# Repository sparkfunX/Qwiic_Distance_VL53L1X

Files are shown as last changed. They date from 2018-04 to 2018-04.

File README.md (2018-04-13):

SparkFun Qwiic 4m Distance Sensor with VL53L1X
========================================

SparkFun Distance Sensor 4m Qwiic - VL53L1X

[*SparkX Distance Sensor 4m (Qwiic) - VL53L1X (SPX-14667)*](https://www.sparkfun.com/products/14667)

The VL53L1X is the latest Time Of Flight (ToF) sensor to be released. It uses a VCSEL (vertical cavity surface emitting laser) to emit a class 1 IR laser and time the reflection to the target. What does all this mean? You can measure the distance to an object up to 4 meters away with millimeter resolution! That’s pretty incredible.

We’re far from done: The VL53L1X is a highly complex sensor with a multitude of options and configurations. We’ve written example sketches that allow you to read the distance, signal rate, and range status. Because ST has chosen not to release a complete datasheet we are forced to reverse engineer the interface from their example code and I2C data stream captures. If you’re into puzzles we could use your help to make the library better!

We’ve found the precision of the sensor to be 1mm but the accuracy is around +/-5mm.

SparkFun labored with love to create this code. Feel like supporting open source hardware? 
Buy a [breakout board](https://www.sparkfun.com/products/14667) from SparkFun!

Repository Contents
-------------------

* **/Documents** - Datasheets
* **/DataCapture** - A capture of the I2C traffic from the ST X-NUCLEO-53L1A1 evaluation kit.
* **/Hardware** - Eagle design files (.brd, .sch)
* **/Software** - Processing Example showing how to manipulate graphics using quaternions

Library
--------------
* **[Arduino Library](https://github.com/sparkfun/SparkFun_VL53L1X_Arduino_Library)** - Library for reading distance in millimeters, signal rate, status, etc.

License Information
-------------------

This product is _**open source**_! 

Please review the LICENSE.md file for license information. 

If you have any questions or concerns on licensing, please contact techsupport@sparkfun.com.

Please use, reuse, and modify these files as you see fit. Please maintain attribution to SparkFun Electronics and release any derivative under the same license.

Distributed as-is; no warranty is given.

- Your friends at SparkFun.

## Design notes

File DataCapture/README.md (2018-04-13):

I2C Data Capture
========================================

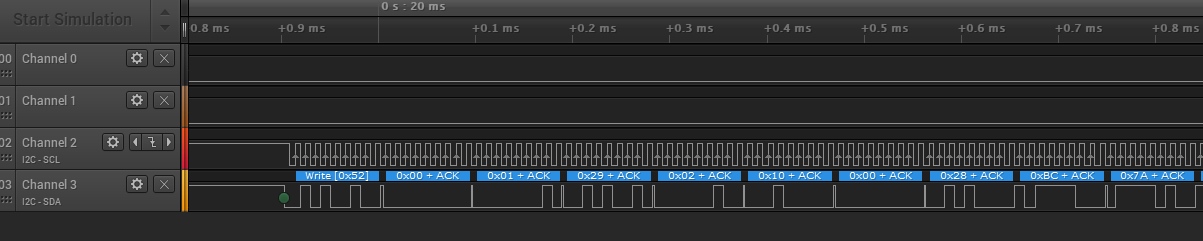
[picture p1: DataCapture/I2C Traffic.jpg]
I2C Traffic from VL53L1X


ST has chosen not to release a full datasheet for the VL53L1X so we must reverse engineer how to talk to the sensor and get measurements. Luckily, ST has provided a C++ example for their STM32 line of processors as well as the X-NUCLEO-53L1A1 development and evaluation board for the VL53L1X. 

SparkFun has written a library based on the I2C traffic between the STM32F401RET6 processor on the Nucleo-64. This zip file contains the I2C traffic recorded when the sensor is configured and activated while using ST's Windows example program (found under [STSW-IMG007](http://www.st.com/content/st_com/en/products/imaging-and-photonics-solutions/proximity-sensors/vl53l1x.html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)). The I2C data was found using a Saleae Logic 4. We've provided a CSV version so that you can use [PulseView](https://sigrok.org/wiki/PulseView) or other open source logic analyzation software.

We would love your help to improve this library. There are many features to this sensor including calibrating cross talk compensation, enabling reference SPADs, establishing the offset, etc. Please create issues and PRs as you go and we'll help out.

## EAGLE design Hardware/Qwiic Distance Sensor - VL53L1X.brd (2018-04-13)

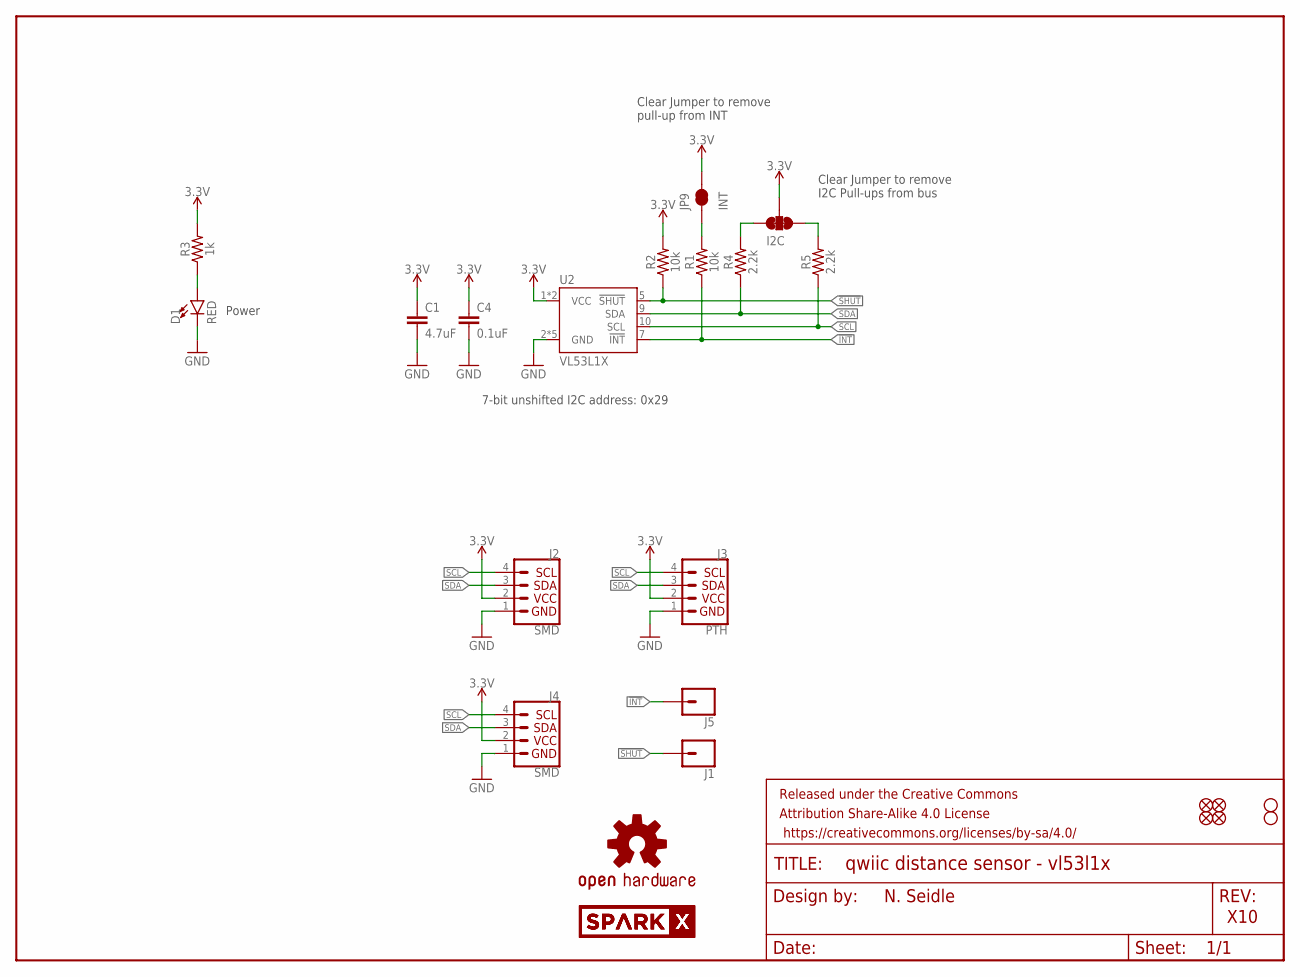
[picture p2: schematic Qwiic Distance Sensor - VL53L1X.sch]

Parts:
C1: 4.7uF; 0603
C4: 0.1uF; 0603
D1: RED; LED-0603
FRAME1: FRAME-LETTER; CREATIVE_COMMONS
I2C: JUMPER-SMT_3_2-NC_TRACE_SILK; SMT-JUMPER_3_2-NC_TRACE_SILK
J1, J5: CONN_01PTH_NO_SILK_YES_STOP; 1X01_NO_SILK
J2, J4: SMD; 1X04_1MM_RA
J3: PTH; 1X04_NO_SILK
JP1, JP2, JP5, JP6: FIDUCIALUFIDUCIAL; MICRO-FIDUCIAL
JP3, JP4: STAND-OFF
JP9: INT; PAD-JUMPER-2-NC_BY_TRACE_YES_SILK
LOGO1: OSHW-LOGOMINI; OSHW-LOGO-MINI
R1, R2: 10k; 0603
R3: 1k; 0603
R4, R5: 2.2k; 0603
U2: VL53L1X
U$1, U$2: SPARKX-LOGO4; SPARKX-MEDIUM

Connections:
3.3V: C1.1, C4.1, I2C.2, J2.2 (VCC), J3.2 (VCC), J4.2 (VCC), JP9.2, R2.2, R3.2, U2.1 (VCC), U2.11 (VCC)
!INT: J5.1, R1.1, U2.7 (!INT)
!SHUT: J1.1, R2.1, U2.5 (!SHUT)
GND: C1.2, C4.2, D1.C, J2.1 (GND), J3.1 (GND), J4.1 (GND), U2.2 (GND), U2.3 (GND), U2.4 (GND), U2.6 (GND), U2.12 (GND)
unnamed: I2C.1, R5.2
unnamed: I2C.3, R4.2
unnamed: D1.A, R3.1
unnamed: JP9.1, R1.2
SCL: J2.4 (SCL), J3.4 (SCL), J4.4 (SCL), R5.1, U2.10 (SCL)
SDA: J2.3 (SDA), J3.3 (SDA), J4.3 (SDA), R4.1, U2.9 (SDA)

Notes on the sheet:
N. Seidle
X10
7-bit unshifted I2C address: 0x29
Clear Jumper to remove I2C Pull-ups from bus
Clear Jumper to remove pull-up from INT
Power

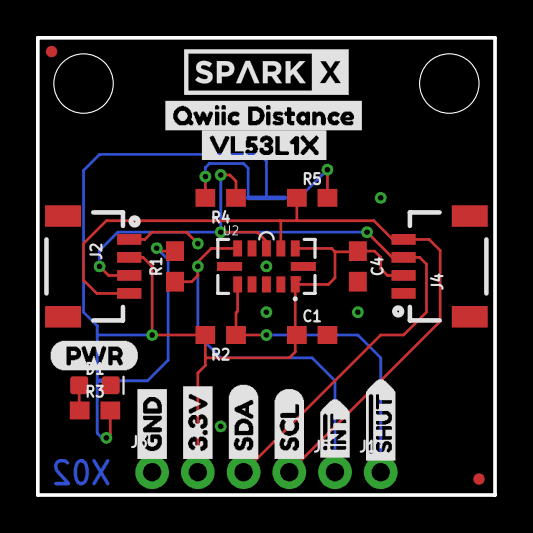
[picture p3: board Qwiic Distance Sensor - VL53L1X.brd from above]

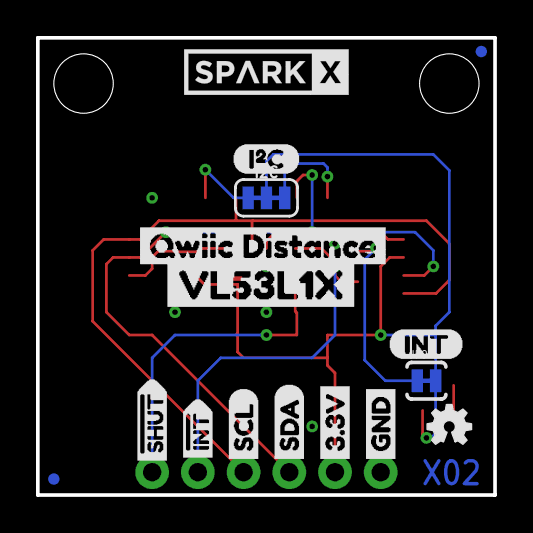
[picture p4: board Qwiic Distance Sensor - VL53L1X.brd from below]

Board: 2 copper layers, 25.4 x 25.4 mm, 45 parts (16 on the bottom side), 10 nets.

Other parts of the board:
U$3, U$22: GND1
U$4, U$21: 3#3V2
U$5, U$27: SDA8
U$6, U$26: SCL9
U$7, U$25: #INT14
U$8, U$9: #SHUT15
U$10: (PWR)
U$11: (I_SUPER2_C)
U$12: (INT)
U$15: QWIIC_DISTANCE7
U$16: VL53L1X8
U$19: QWIIC_DISTANCE9
U$20: VL53L1X10

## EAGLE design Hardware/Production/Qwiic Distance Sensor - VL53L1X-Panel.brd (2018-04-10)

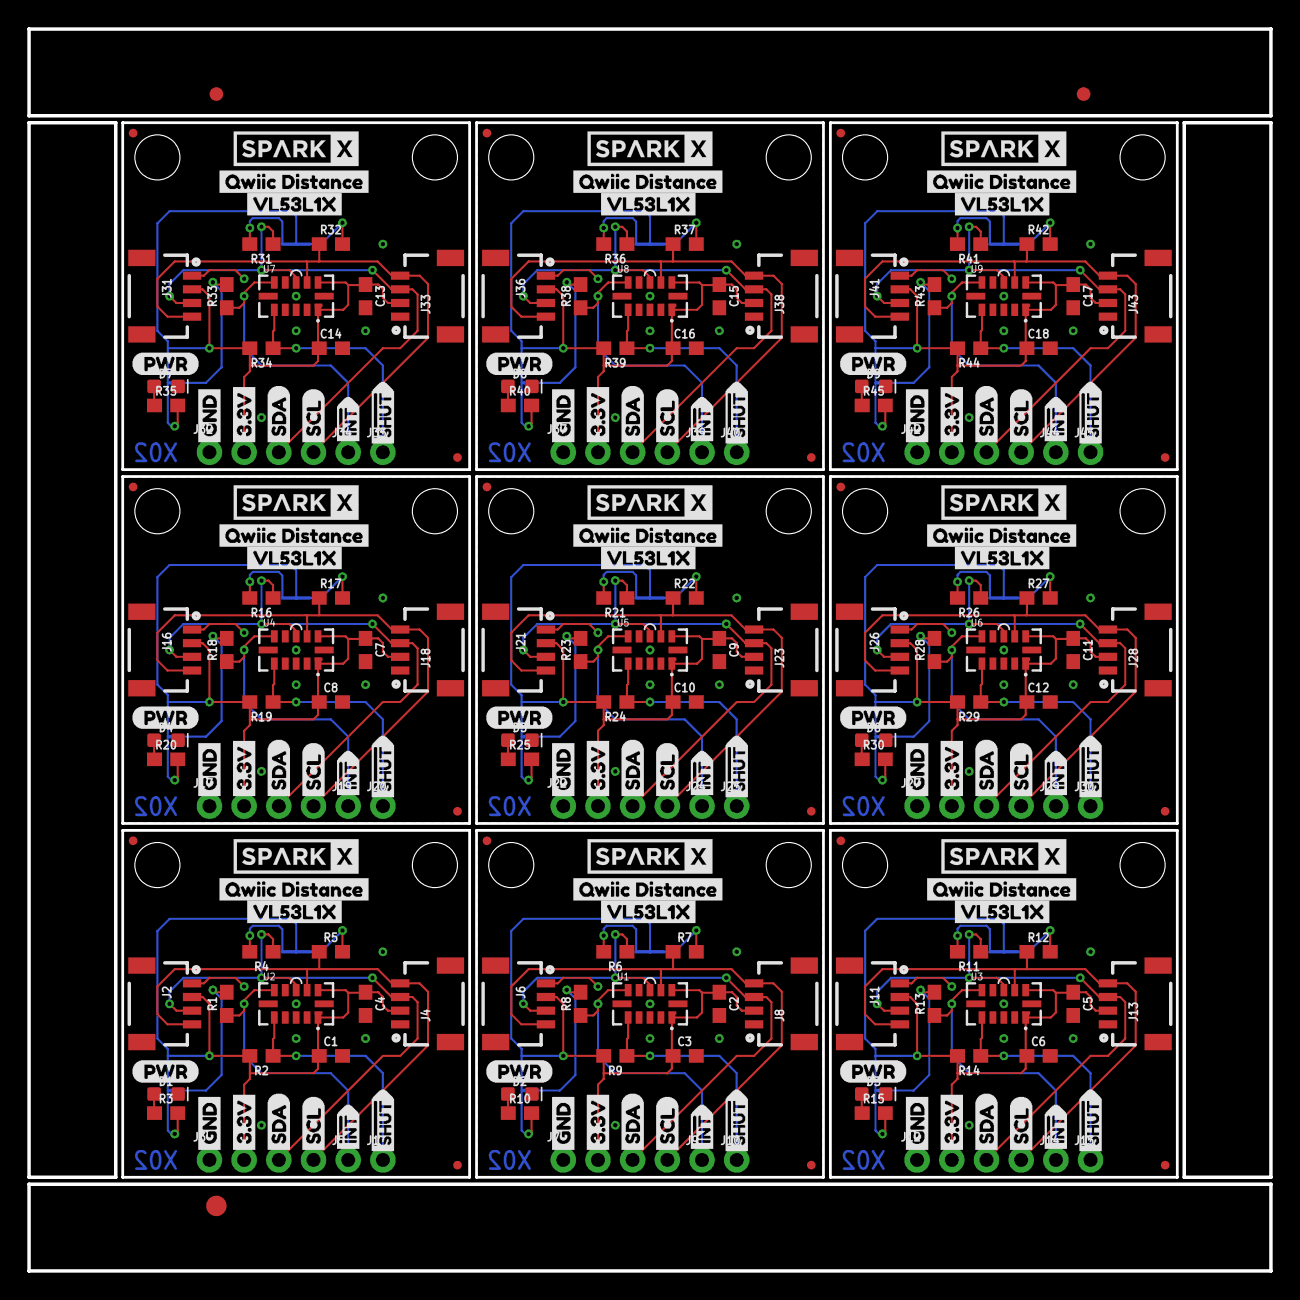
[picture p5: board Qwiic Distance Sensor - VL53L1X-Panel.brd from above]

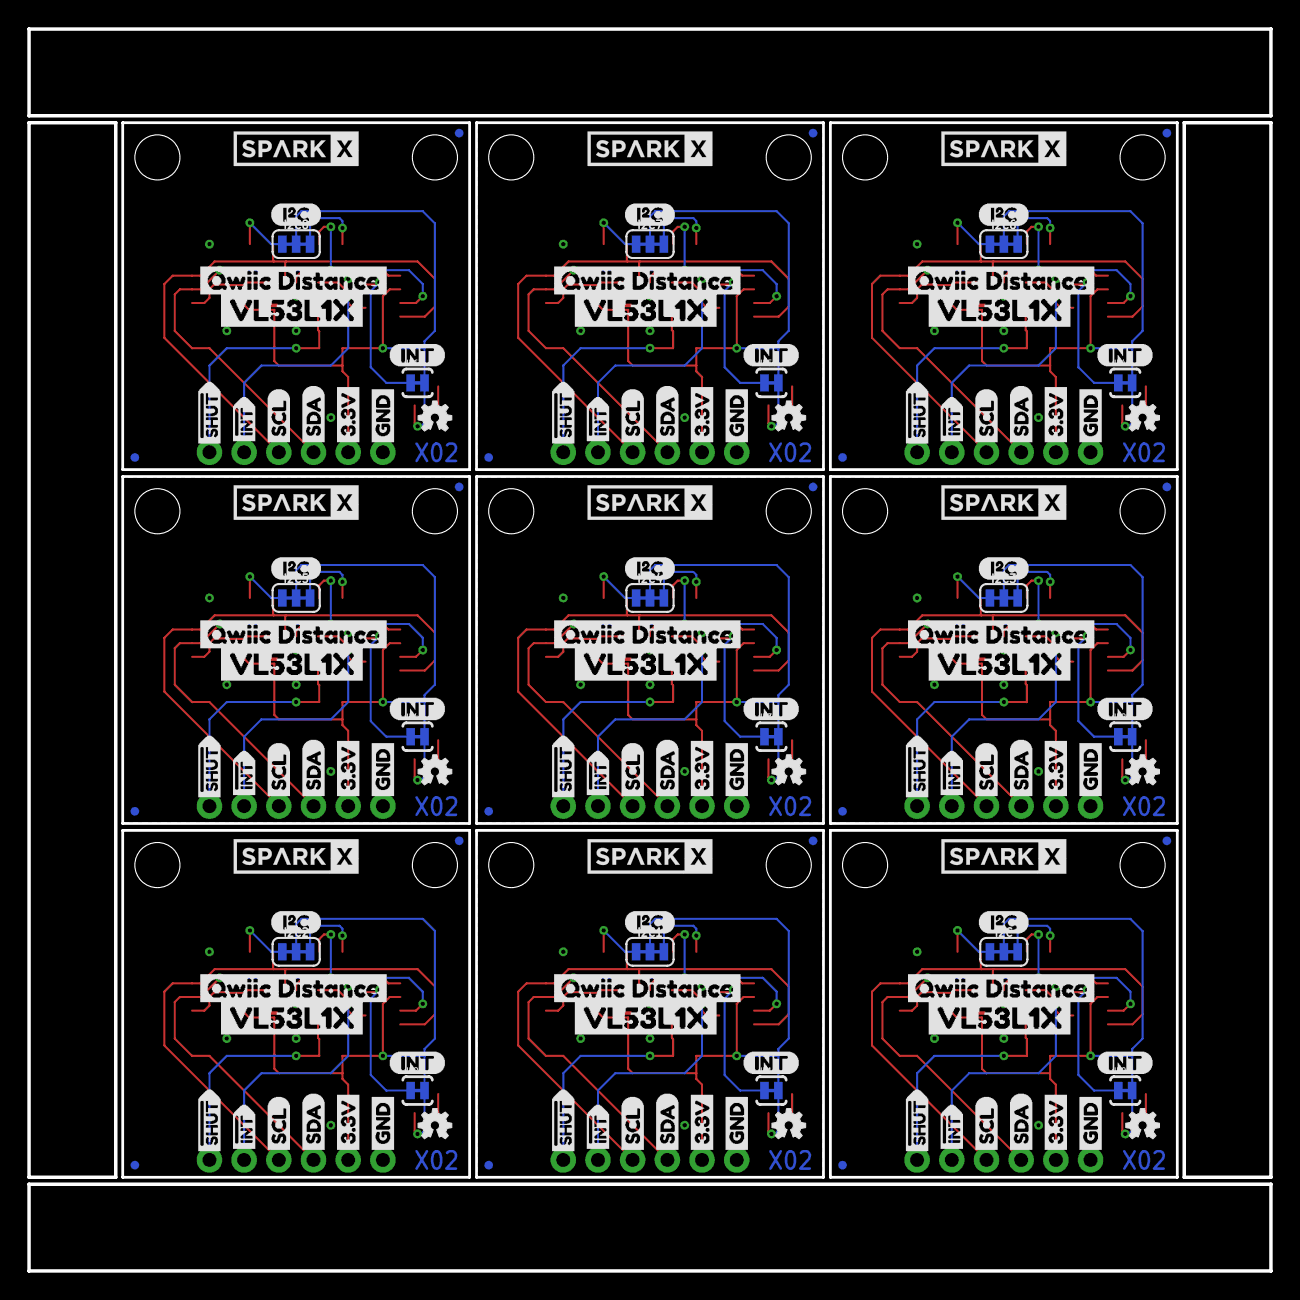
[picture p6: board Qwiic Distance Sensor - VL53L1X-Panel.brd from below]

Board: 2 copper layers, 90.9 x 90.9 mm, 399 parts (144 on the bottom side), 90 nets.

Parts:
C1, C3, C6, C8, C10, C12, C14, C16, C18: 4.7uF; 0603
C2, C4, C5, C7, C9, C11, C13, C15, C17: 0.1uF; 0603
D1, D2, D3, D4, D5, D6, D7, D8, D9: RED; LED-0603
E$1, E$2: FIDUCIAL-1X2
E$3: FIDUCIAL-1.5X3
I2C, I2C1, I2C2, I2C3, I2C4, I2C5, I2C6, I2C7, I2C8: SMT-JUMPER_3_2-NC_TRACE_SILK
J1, J5, J9, J10, J14, J15, J19, J20, J24, J25, J29, J30, J34, J35, J39, J40, J44, J45: 1X01_NO_SILK
J2, J4, J6, J8, J11, J13, J16, J18, J21, J23, J26, J28, J31, J33, J36, J38, J41, J43: SMD; 1X04_1MM_RA
J3, J7, J12, J17, J22, J27, J32, J37, J42: PTH; 1X04_NO_SILK
JP1, JP2, JP5, JP6, JP10, JP11, JP12, JP13, JP17, JP18, JP19, JP20, JP24, JP25, JP26, JP27, JP31, JP32, JP33, JP34, JP38, JP39, JP40, JP41, JP45, JP46, JP47, JP48, JP52, JP53, JP54, JP55, JP59, JP60, JP61, JP62: FIDUCIALUFIDUCIAL; MICRO-FIDUCIAL
JP3, JP4, JP7, JP8, JP15, JP16, JP22, JP23, JP29, JP30, JP36, JP37, JP43, JP44, JP50, JP51, JP57, JP58: STAND-OFF
JP9, JP14, JP21, JP28, JP35, JP42, JP49, JP56, JP63: INT; PAD-JUMPER-2-NC_BY_TRACE_YES_SILK
LOGO1, LOGO2, LOGO3, LOGO4, LOGO5, LOGO6, LOGO7, LOGO8, LOGO9: OSHW-LOGOMINI; OSHW-LOGO-MINI
R1, R2, R8, R9, R13, R14, R18, R19, R23, R24, R28, R29, R33, R34, R38, R39, R43, R44: 10k; 0603
R3, R10, R15, R20, R25, R30, R35, R40, R45: 1k; 0603
R4, R5, R6, R7, R11, R12, R16, R17, R21, R22, R26, R27, R31, R32, R36, R37, R41, R42: 2.2k; 0603
U1, U2, U3, U4, U5, U6, U7, U8, U9: VL53L1XSMD; VL53L1X
U$1, U$2, U$13, U$14, U$43, U$44, U$64, U$65, U$85, U$86, U$106, U$107, U$127, U$128, U$148, U$149, U$169, U$170: SPARKX-LOGO4; SPARKX-MEDIUM
U$3, U$22, U$29, U$33, U$50, U$54, U$71, U$75, U$92, U$96, U$113, U$117, U$134, U$138, U$155, U$159, U$176, U$180: GND1
U$4, U$21, U$28, U$34, U$49, U$55, U$70, U$76, U$91, U$97, U$112, U$118, U$133, U$139, U$154, U$160, U$175, U$181: 3#3V2
U$5, U$27, U$32, U$35, U$53, U$56, U$74, U$77, U$95, U$98, U$116, U$119, U$137, U$140, U$158, U$161, U$179, U$182: SDA8
U$6, U$26, U$31, U$36, U$52, U$57, U$73, U$78, U$94, U$99, U$115, U$120, U$136, U$141, U$157, U$162, U$178, U$183: SCL9
U$7, U$25, U$30, U$37, U$51, U$58, U$72, U$79, U$93, U$100, U$114, U$121, U$135, U$142, U$156, U$163, U$177, U$184: #INT14
U$8, U$9, U$38, U$39, U$59, U$60, U$80, U$81, U$101, U$102, U$122, U$123, U$143, U$144, U$164, U$165, U$185, U$186: #SHUT15
U$10, U$40, U$61, U$82, U$103, U$124, U$145, U$166, U$187: (PWR)
U$11, U$41, U$62, U$83, U$104, U$125, U$146, U$167, U$188: (I_SUPER2_C)
U$12, U$42, U$63, U$84, U$105, U$126, U$147, U$168, U$189: (INT)
U$15, U$17, U$45, U$66, U$87, U$108, U$129, U$150, U$171: QWIIC_DISTANCE7
U$16, U$18, U$46, U$67, U$88, U$109, U$130, U$151, U$172: VL53L1X8
U$19, U$23, U$47, U$68, U$89, U$110, U$131, U$152, U$173: QWIIC_DISTANCE9
U$20, U$24, U$48, U$69, U$90, U$111, U$132, U$153, U$174: VL53L1X10

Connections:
3.3V: C1.1, C4.1, I2C.2, J2.2, J3.2, J4.2, JP9.2, R2.2, R3.2, U2.1, U2.11
3.3V1: C2.1, C3.1, I2C1.2, J6.2, J7.2, J8.2, JP14.2, R9.2, R10.2, U1.1, U1.11
3.3V2: C5.1, C6.1, I2C2.2, J11.2, J12.2, J13.2, JP21.2, R14.2, R15.2, U3.1, U3.11
3.3V3: C7.1, C8.1, I2C3.2, J16.2, J17.2, J18.2, JP28.2, R19.2, R20.2, U4.1, U4.11
3.3V4: C9.1, C10.1, I2C4.2, J21.2, J22.2, J23.2, JP35.2, R24.2, R25.2, U5.1, U5.11
3.3V5: C11.1, C12.1, I2C5.2, J26.2, J27.2, J28.2, JP42.2, R29.2, R30.2, U6.1, U6.11
3.3V6: C13.1, C14.1, I2C6.2, J31.2, J32.2, J33.2, JP49.2, R34.2, R35.2, U7.1, U7.11
3.3V7: C15.1, C16.1, I2C7.2, J36.2, J37.2, J38.2, JP56.2, R39.2, R40.2, U8.1, U8.11
3.3V8: C17.1, C18.1, I2C8.2, J41.2, J42.2, J43.2, JP63.2, R44.2, R45.2, U9.1, U9.11
!INT: J5.1, R1.1, U2.7
!INT1: J9.1, R8.1, U1.7
!INT2: J14.1, R13.1, U3.7
!INT3: J19.1, R18.1, U4.7
!INT4: J24.1, R23.1, U5.7
!INT5: J29.1, R28.1, U6.7
!INT6: J34.1, R33.1, U7.7
!INT7: J39.1, R38.1, U8.7
!INT8: J44.1, R43.1, U9.7
!SHUT: J1.1, R2.1, U2.5
!SHUT1: J10.1, R9.1, U1.5
!SHUT2: J15.1, R14.1, U3.5
!SHUT3: J20.1, R19.1, U4.5
!SHUT4: J25.1, R24.1, U5.5
!SHUT5: J30.1, R29.1, U6.5
!SHUT6: J35.1, R34.1, U7.5
!SHUT7: J40.1, R39.1, U8.5
!SHUT8: J45.1, R44.1, U9.5
GND: C1.2, C4.2, D1.C, J2.1, J3.1, J4.1, U2.2, U2.3, U2.4, U2.6, U2.12
GND1: C2.2, C3.2, D2.C, J6.1, J7.1, J8.1, U1.2, U1.3, U1.4, U1.6, U1.12
GND2: C5.2, C6.2, D3.C, J11.1, J12.1, J13.1, U3.2, U3.3, U3.4, U3.6, U3.12
GND3: C7.2, C8.2, D4.C, J16.1, J17.1, J18.1, U4.2, U4.3, U4.4, U4.6, U4.12
GND4: C9.2, C10.2, D5.C, J21.1, J22.1, J23.1, U5.2, U5.3, U5.4, U5.6, U5.12
GND5: C11.2, C12.2, D6.C, J26.1, J27.1, J28.1, U6.2, U6.3, U6.4, U6.6, U6.12
GND6: C13.2, C14.2, D7.C, J31.1, J32.1, J33.1, U7.2, U7.3, U7.4, U7.6, U7.12
GND7: C15.2, C16.2, D8.C, J36.1, J37.1, J38.1, U8.2, U8.3, U8.4, U8.6, U8.12
GND8: C17.2, C18.2, D9.C, J41.1, J42.1, J43.1, U9.2, U9.3, U9.4, U9.6, U9.12
unnamed: I2C.1, R5.2
unnamed: I2C.3, R4.2
unnamed: D1.A, R3.1
unnamed: JP9.1, R1.2
unnamed: I2C1.1, R7.2
unnamed: I2C1.3, R6.2
unnamed: JP14.1, R8.2
unnamed: D2.A, R10.1
unnamed: I2C2.1, R12.2
unnamed: I2C2.3, R11.2
unnamed: JP21.1, R13.2
unnamed: D3.A, R15.1
unnamed: I2C3.1, R17.2
unnamed: I2C3.3, R16.2
unnamed: JP28.1, R18.2
unnamed: D4.A, R20.1
unnamed: I2C4.1, R22.2
unnamed: I2C4.3, R21.2
unnamed: JP35.1, R23.2
unnamed: D5.A, R25.1
unnamed: I2C5.1, R27.2
unnamed: I2C5.3, R26.2
unnamed: JP42.1, R28.2
unnamed: D6.A, R30.1
unnamed: I2C6.1, R32.2
unnamed: I2C6.3, R31.2
unnamed: JP49.1, R33.2
unnamed: D7.A, R35.1
unnamed: I2C7.1, R37.2
unnamed: I2C7.3, R36.2
unnamed: JP56.1, R38.2
unnamed: D8.A, R40.1
unnamed: I2C8.1, R42.2
unnamed: I2C8.3, R41.2
unnamed: JP63.1, R43.2
unnamed: D9.A, R45.1
SCL: J2.4, J3.4, J4.4, R5.1, U2.10
SCL1: J6.4, J7.4, J8.4, R7.1, U1.10
SCL2: J11.4, J12.4, J13.4, R12.1, U3.10
SCL3: J16.4, J17.4, J18.4, R17.1, U4.10
SCL4: J21.4, J22.4, J23.4, R22.1, U5.10
SCL5: J26.4, J27.4, J28.4, R27.1, U6.10
SCL6: J31.4, J32.4, J33.4, R32.1, U7.10
SCL7: J36.4, J37.4, J38.4, R37.1, U8.10
SCL8: J41.4, J42.4, J43.4, R42.1, U9.10
SDA: J2.3, J3.3, J4.3, R4.1, U2.9
SDA1: J6.3, J7.3, J8.3, R6.1, U1.9
SDA2: J11.3, J12.3, J13.3, R11.1, U3.9
SDA3: J16.3, J17.3, J18.3, R16.1, U4.9
SDA4: J21.3, J22.3, J23.3, R21.1, U5.9
SDA5: J26.3, J27.3, J28.3, R26.1, U6.9
SDA6: J31.3, J32.3, J33.3, R31.1, U7.9
SDA7: J36.3, J37.3, J38.3, R36.1, U8.9
SDA8: J41.3, J42.3, J43.3, R41.1, U9.9

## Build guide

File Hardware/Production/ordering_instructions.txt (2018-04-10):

panel size, 91x91mm
PCB thickness, 1.6mm
number of layers, 2
soldermask color, Black
silkscreen color, White
oz copper, 1oz
finish, HASL lead free
stencils, top

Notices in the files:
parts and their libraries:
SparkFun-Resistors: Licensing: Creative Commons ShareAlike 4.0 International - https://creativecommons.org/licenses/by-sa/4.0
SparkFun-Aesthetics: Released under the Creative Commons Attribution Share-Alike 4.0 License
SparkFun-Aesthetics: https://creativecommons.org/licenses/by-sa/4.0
